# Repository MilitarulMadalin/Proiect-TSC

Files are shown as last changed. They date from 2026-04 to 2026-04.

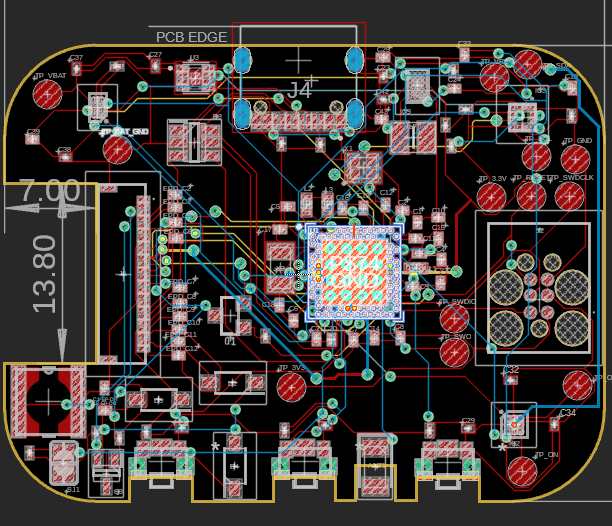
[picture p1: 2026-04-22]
Images/2d.png

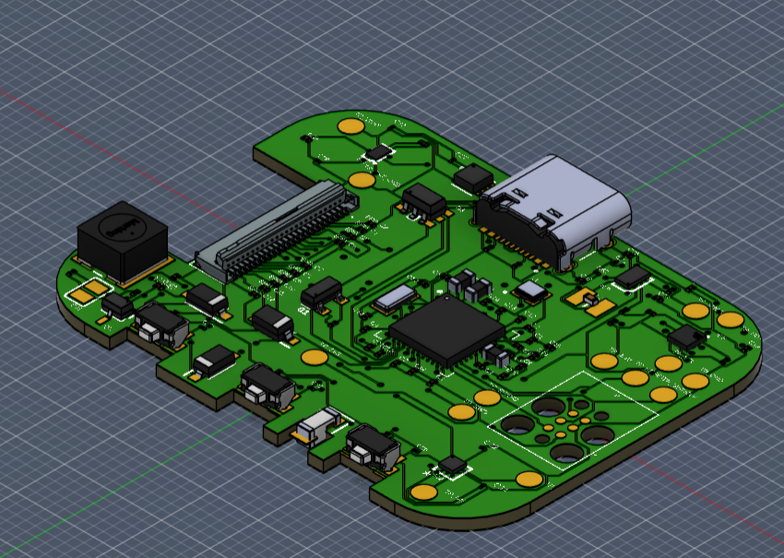
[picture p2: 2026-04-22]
Images/exploded.png

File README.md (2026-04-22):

# InkTime

## Cuprins

1. [Schemă bloc](#1-schemă-bloc)
2. [Bill of Materials (BOM)](#2-bill-of-materials-bom)
3. [Descrierea hardware detaliată](#3-descrierea-hardware-detaliată)
4. [Mapare pini nRF52840](#4-mapare-pini-nrf52840)
5. [Design log](#5-decizii-de-design)

---

## 1. Schemă bloc

```
                  +--------------+      +-------------+
                  |   E-Paper    |      |    LiPo     |
                  |  Drive Circ. |      |   Charger   +
                  +------+-------+      +------+------+
                         |                     |
                         | EPD_PINS            | I2C, PMIC_INT       +-----------+
                         v                     |                     |   Fuel    |
  +-----------+   +--------------+             |            I2C      |   Gauge   |
  |  E-Paper  |<--+   E-Paper    |             |        +----------->|           |
  |   1.5"    |   |    Conn.     |             |        |            +-----------+
  +-----------+   +------+-------+             |        |
                         |                     |        |            +-----------+
                         |  SPI                |        |            |   USB-C   |
                         v                     v        |            |    J4     |
                  +----------------------------+--------+------+     +-----+-----+
                  |                                            |           |
                  |              nRF52840   (U1)               |<----------+
                  |                                            |  D+, D-
                  |                                            |<--------+
                  +--+--------+--------+--------+------+-------+         |
                     |        |        |        |      |                 |
                     | I2C    | I2C    | ANT1   | SWD  | 3xGPIO          | D+, D-
                     |        | HAPT.  |        |      |                 |
                     v        | EN     v        v      v           +-----+-----+
                  +-------+   |   +--------+ +-----+ +---------+   |    ESD    |
                  |  IMU  |   |   | Antena | | SWD | | Butoane |   | Protection|
                  |BMA423 |   |   |  2.4   | | J2  | +---------+   +-----------+
                  +-------+   |   +--------+ +-----+
                              v
                          +-------+
                          |Haptic |
                          |DRV2605|
                          +-------+
```

---

## 2. Bill of Materials (BOM)

| Desig. (ref.) | Valoare / Part Number | Funcție în circuit | Pachet | Cant. | JLCPCB | Datasheet |
|---|---|---|---|---|---|---|
| U1 | nRF52840-QIAA | MCU BLE 5 / 2.4 GHz, Cortex-M4F, 1 MB Flash  | aQFN73 | 1 | [C190794](https://jlcpcb.com/partdetail/C190794) | [PDF](https://infocenter.nordicsemi.com/pdf/nRF52840_PS_v1.7.pdf) |
| IC1 | BQ25180YBGR | Încărcător LiPo 1-cell, programabil I2C | DSBGA-8 0.4mm | 1 | [C965556](https://jlcpcb.com/partdetail/C965556) | [PDF](https://www.ti.com/lit/ds/symlink/bq25180.pdf) |
| U3 | MAX17048G+T10 | Fuel gauge ModelGauge 1-cell, I2C | TDFN-8 | 1 | [C129977](https://jlcpcb.com/partdetail/C129977) | [PDF](https://www.analog.com/media/en/technical-documentation/data-sheets/MAX17048-MAX17049.pdf) |
| IC9 | RT6160AWSC | Buck-Boost 3V3, 2A (rail principal) | WL-CSP-15 | 1 | [C58559](https://jlcpcb.com/partdetail/C58559) | [PDF](https://www.richtek.com/assets/product_file/RT6160A/DS6160A-02.pdf) |
| IC3 | BMA423 | Accelerometru 3-axis, step counter, wrist-tilt | LGA-12 | 1 | [C553690](https://jlcpcb.com/partdetail/C553690) | [PDF](https://www.bosch-sensortec.com/media/boschsensortec/downloads/datasheets/bst-bma423-ds000.pdf) |
| IC2 | DRV2605YZFR | Driver haptic ERM/LRA, 123 efecte, I2C | DSBGA-9 | 1 | [C92482](https://jlcpcb.com/partdetail/C92482) | [PDF](https://www.ti.com/lit/ds/symlink/drv2605.pdf) |
| Q1 | DMG2305UX-7 (20V/4.2A) | P-MOSFET load-switch rail EPD | SOT-23 | 1 | [C114005](https://jlcpcb.com/partdetail/C114005) | [PDF](https://www.diodes.com/assets/Datasheets/DMG2305UX.pdf) |
| Q3 | SI1308EDL-T1-GE3 | N-MOSFET pentru boost charge-pump EPD | SOT-23 | 1 | [C294574](https://jlcpcb.com/partdetail/C294574) | [PDF](https://www.vishay.com/docs/66632/si1308edl.pdf) |
| D3 | USBLC6-2SC6Y | TVS diode array, protecție ESD pe USB D± | SOT-23-6 | 1 | [C7519](https://jlcpcb.com/partdetail/C7519) | [PDF](https://www.st.com/resource/en/datasheet/usblc6-2.pdf) |
| D2, D4, D5 | MBR0530 | Diodă Schottky 30V pentru charge-pump EPD | SOD-123 | 3 | [C131850](https://jlcpcb.com/partdetail/C131850) | [PDF](https://www.onsemi.com/pdf/datasheet/mbr0520-d.pdf) |
| ANT1 | 2450AT18B100E | Antenă ceramică chip 2.4 GHz, Johanson | 3216 | 1 | [C76907](https://jlcpcb.com/partdetail/C76907) | [PDF](https://www.johansontechnology.com/datasheets/2450AT18B100E.pdf) |
| X1 | NX2016SA 32 MHz ±10 ppm | Cristal HF pentru radio și CPU | 2016 | 1 | [C255982](https://jlcpcb.com/partdetail/C255982) | [PDF](https://www.ndk.com/images/products/catalog/c_NX2016SA-STD-CRA-2_e.pdf) |
| X2 | ABS07-120 32.768 kHz | Cristal LF pentru RTC (low-power) | 3215 | 1 | [C32346](https://jlcpcb.com/partdetail/C32346) | [PDF](https://abracon.com/Resonators/abs07-120.pdf) |
| L1 | 3.9 nH | RF match filtru π — inductor serie antenă | 0402 | 1 | [C1789](https://jlcpcb.com/partdetail/C1789) | — |
| L3 | 15 nH | RF match filtru π — inductor paralel | 0402 | 1 | [C1794](https://jlcpcb.com/partdetail/C1794) | — |
| L2 | 10 µH | DCDC intern nRF52840 (pin DCC) | 0402 | 1 | [C1046](https://jlcpcb.com/partdetail/C1046) | — |
| L5 | WE-TPC 744043680, 68 µH | Boost e-paper (rail VGH / VGL) | 4828 | 1 | [C492815](https://jlcpcb.com/partdetail/C492815) | [PDF](https://www.we-online.com/catalog/datasheet/744043680.pdf) |
| L7 | FTC252012SR47MBCA, 0.47 µH | Inductor putere pentru RT6160 | 2520 | 1 | [C123046](https://jlcpcb.com/partdetail/C123046) | — |
| J4 | KH-TYPE-C-16P | Conector USB-C receptacle (16 pini) | SMT | 1 | [C165948](https://jlcpcb.com/partdetail/C165948) | — |
| J1 | Molex 503480-2400 | Conector baterie LiPo, 2-pin pitch 1.5 mm | SMT | 1 | [C518439](https://jlcpcb.com/partdetail/C518439) | [PDF](https://www.molex.com/pdm_docs/sd/5034802400_sd.pdf) |
| J2 | TC2030-IDC (Tag-Connect) | Footprint debug SWD (pogo-pins, fără receptacle) | — | 1 | (doar footprint) | [PDF](https://www.tag-connect.com/wp-content/uploads/bsk-pdf-manager/TC2030-IDC.pdf) |
| SW_UP, SW_DN, SW_ENT | EVP-AKE31A | Buton tactil side-push 4.5×3.5 mm | SMT | 3 | [C719888](https://jlcpcb.com/partdetail/C719888) | [PDF](https://industrial.panasonic.com/cdbs/www-data/pdf/ATV0000/ATV0000CE11.pdf) |
| C11, C12 | 100 nF / 10V (X7R) | Decuplare locală IC-uri digitale | 0201 | 2 | [C106250](https://jlcpcb.com/partdetail/C106250) | — |
| C5, C7, C8 | 100 µF / 6.3V | Bulk buck-boost RT6160 | 0201 | 3 | [C19702](https://jlcpcb.com/partdetail/C19702) | — |
| C19 | 100 µF / 6.3V | Bulk rail VBAT | 0201 | 1 | [C19702](https://jlcpcb.com/partdetail/C19702) | — |
| C6, C14, C20, C21 | 4.7 µF / 10V (X7R) | Decuplare nRF (DEC*) | 0201 | 4 | [C19666](https://jlcpcb.com/partdetail/C19666) | — |
| C15 | 1.0 µF / 10V | Decuplare VREG nRF | 0201 | 1 | [C15849](https://jlcpcb.com/partdetail/C15849) | — |
| C39 | 10 µF / 6.3V | Bulk IC1 (charger) | 0201 | 1 | [C15850](https://jlcpcb.com/partdetail/C15850) | — |
| C43 | 4.7 µF | Intrare IC2 (driver haptic) | 0201 | 1 | [C19666](https://jlcpcb.com/partdetail/C19666) | — |
| C1-EP-DR, C24 | 10 µF | Filtre intrare driver EPD / RT6160 | 0201 | 2 | [C15850](https://jlcpcb.com/partdetail/C15850) | — |
| C2-EP-DR | 4.7 µF / 25V | Bulk intrare boost EPD | 0201 | 1 | [C19666](https://jlcpcb.com/partdetail/C19666) | — |
| C25, C33 | 22 µF | Ieșire RT6160 (3V3) | 0201 | 2 | [C45783](https://jlcpcb.com/partdetail/C45783) | — |
| C17, C18 | 12 µF | Filtre DCDC intern nRF | 0201 | 2 | [C162698](https://jlcpcb.com/partdetail/C162698) | — |
| C16 | 47 nF | Filtru control-loop RT6160 | 0201 | 1 | [C113010](https://jlcpcb.com/partdetail/C113010) | — |
| C9 | 820 pF | Decuplare DEC6 nRF | 0201 | 1 | [C1603](https://jlcpcb.com/partdetail/C1603) | — |
| C1, C2 | 12 pF (NP0 / C0G) | Load-caps pentru X1 (32 MHz) | 0201 | 2 | [C1570](https://jlcpcb.com/partdetail/C1570) | — |
| C3, C4 | 1 pF | RF match (π) — shunt | 0201 | 2 | [C1552](https://jlcpcb.com/partdetail/C1552) | — |
| C10, C13, C22 | N.C. (Not Connected) | Rezervate — neplasate la fabricație | 0201 | 3 | (nu se lipește) | — |
| C23, C27, C29, C30, C31, C32, C34, C37, C38, C42 | GRM011R60J152KE01L, 1.5 nF | Filtre RF / bypass high-freq | 0201 | 10 | [C400827](https://jlcpcb.com/partdetail/C400827) | [PDF](https://www.murata.com/en-us/products/productdata/8796840689694/GCM155C71A225KE36-01A.pdf)  |
| EPD_C1, EPD_C2, EPD_C6, EPD_C7, EPD_C8, EPD_C9, EPD_C10, EPD_C11, EPD_C12 | 1 µF / 50V (X7R) | Flying caps charge-pump pentru VGH/VGL | 0201 | 9 | [C105948](https://jlcpcb.com/partdetail/C105948) | — |
| EPD_C5 | 0.1 µF / 50V | Decuplare driver EPD | 0201 | 1 | [C14663](https://jlcpcb.com/partdetail/C14663) | — |
| R1_USB, R2_USB | 5.1 kΩ 1% (CC1 / CC2) | Pull-down USB-C — configurare device UFP | 0201 | 2 | [C98220](https://jlcpcb.com/partdetail/C98220) | — |
| R1_EP_DR, R2_EP_DR | 10 kΩ 1% | Divider / gate pull pentru boost EPD | 0201 | 2 | [C25744](https://jlcpcb.com/partdetail/C25744) | — |
| R_PWR_EPD, R_TYPE_SEL | 10 kΩ 1% | Selector tip panou EPD / enable rail | 0201 | 2 | [C25744](https://jlcpcb.com/partdetail/C25744) | — |
| R2, R3, R4 | 0 Ω | Jumperi / pull-uri I2C (SDA, SCL, ALERT) | 0201 | 3 | [C17168](https://jlcpcb.com/partdetail/C17168) | — |
| R5, R7, R8 | 10 kΩ 1% | Pull-up butoane SW_UP, SW_DN, SW_ENT | 0201 | 3 | [C25744](https://jlcpcb.com/partdetail/C25744) | — |
| R9 | 10 kΩ 1% | MR (TS / mode-select) pe BQ25180 | 0201 | 1 | [C25744](https://jlcpcb.com/partdetail/C25744) | — |
| R17, R18 | 3.3 kΩ 1% | Feedback / setare tensiune RT6160 | 0201 | 2 | [C22975](https://jlcpcb.com/partdetail/C22975) | — |
| TP_3V3, TP_3.3V, TP_VREG, TP_VBAT, TP_BAT_GND, TP_GND, TP_RESET, TP_SDA, TP_SCL, TP_SWDCLK, TP_SWDIO, TP_SWO, TP_ON, TP_OP | Pad 20 mil | Puncte de test pentru măsurători / debug | 20R pad | 14 | (doar footprint) | — |
| SJ1 | Solder jumper | Select hardware (bootloader / mod) | 0201 jumper | 1 | (doar footprint) | — |

### Off-board

| Componentă | Valoare / Model | Legătură |
|---|---|---|
| Baterie | LiPo 483450, 3.7V, 2400 mAh | Conector J1 (Molex 503480-2400) |
| Panou e-paper | GDEW0154M09, 1.54" 200×200 px, SPI | Conector FPC 24 pini (nu e pe placă — se leagă prin cablaj) |
| Motor vibrație | ERM 10×2.7 mm, 3V nominal | Pini OUT+ / OUT− ai DRV2605 |

---

## 3. Descrierea hardware detaliată

### 3.1. Alimentare

Lanțul de alimentare respectă o arhitectură clasică **charger → baterie → regulator**, adaptată pentru low-power:

1. **Intrare USB-C (J4)** — 5V / max 500 mA. Liniile D+/D− sunt protejate de **USBLC6-2 (D3)**, diodă TVS cu capacitate mică care nu afectează eye-pattern-ul USB 2.0 Full-Speed.
2. **Încărcător BQ25180 (IC1)** — integrează charger liniar 1-cell LiPo cu până la 500 mA, path management, detecție over-voltage 18V și **ship-mode**. Configurabil pe I2C: curent de încărcare, prag de terminare, temperatură. Pinul **INT** este conectat la nRF pentru evenimente.
3. **Baterie LiPo 2400 mAh** conectată la J1. Pinul TS/MR al BQ25180 nu folosește termistor.
4. **Fuel gauge MAX17048 (U3)** — măsoară direct tensiunea bateriei cu algoritmul **ModelGauge**, oferind SoC și rata de descărcare. Pinul ALERT este rutat la nRF pentru notificări de low-battery.
5. **Buck-Boost RT6160 (IC9)** — convertor **step-up/step-down** la **3V3 fix**, eficiență până la 95%. Alegerea unui buck-boost e critică: o baterie LiPo ajunge la ~3.0V la descărcare, iar un LDO ar avea dropout, în timp ce un buck pur nu ar putea menține 3V3 când bateria e sub acest nivel. RT6160 oferă continuitate până la ~2.5V cu regulare menținută.
6. **Load-switch Q1 (DMG2305UX-7)** — P-MOSFET care deconectează complet rail-ul boost al e-paper-ului în stand-by.

**Rețeaua RF**: antena ceramică ANT1 e alimentată prin **filtru π** pentru match la 50 Ω și filtrare armonici. Traseul de la pinul **ANT** al nRF la antenă respectă **controlled impedance** 50 Ω.

### 3.2. Microcontroller și clock

**nRF52840** rulează cu două cristale:

- **X1 = 32 MHz (NX2016SA)** pe pinii XC1/XC2, cristal principal pentru radio și HFCLK. Toleranță ≤ 40 ppm.
- **X2 = 32.768 kHz (ABS07)** pe pinii P0.00/XL1, P0.01/XL2, clock low-power pentru RTC și sleep. Toleranță 20 ppm, consum < 1 µA.

Decuplarea rail-urilor interne folosește 4.7 µF + 100 nF + 1 µF + 100 pF conform reference design Nordic. **L4 + L6**împreună cu C14 + C15 + C20 implementează DC/DC intern care reduce consumul cu ~30% față de modul LDO.

### 3.3. Display e-paper

E-paper-ul **GDEW0154M09** are nevoie de patru rail-uri: +15V (VGH), −15V (VGL), +22V (VPP), −20V (VEE). Driver circuit-ul de pe Sheet 2 folosește:

- **Boost cu SI1308 + L5 + MBR0530** care generează VGH/VGL prin charge-pump multi-stage.
- **9× condensatori 1µF/50V** — flying caps pentru stagele charge-pump.

Controlul e pe SPI + semnale discrete: RST, BUSY, D/C, CS. Rail-ul EPD_3V3 se activează doar când se refresh-uiește display-ul; în rest, e-paper-ul menține imaginea fără alimentare.

### 3.4. Senzori și actuatori

- **BMA423 (IC3)** — accelerometru 3-axis 12-bit cu engine de pași, detecție tap/double-tap și wrist-tilt. Întreruperi: INT1, INT2. Interfața I2C, adresa 0x19.
- **DRV2605 (IC2)** — driver haptic pentru motoare ERM sau LRA. Conține **librărie pre-programată cu 123 efecte**, plus mod real-time. Activat prin HAPTIC_EN pentru a elimina complet consumul în idle. Bobina motorului e conectată la pinii OUT+/OUT−.

### 3.5. Butoane și debug

Cele 3 butoane sunt conectate GPIO cu GND, cu pull-up intern activat software. **Fără debounce hardware** , se face în firmware.

Conectorul **TC2030-IDC (J2)** e un footprint 6-pin fără receptacle fizic, debugger-ul are pogo-pins care fac contact direct pe PCB, economisind componenta și spațiu. Semnale: SWDIO, SWDCLK, SWO, RESET, 3V3, GND.

---

## 4. Mapare pini nRF52840

Mapare extrasă din schematic (InkTime v6, Sheet 1 + Sheet 2):

| Pin nRF52840 | Nume net | Funcție firmware | Destinație periferic |
|---|---|---|---|
| **Alimentare**  | | | |
| VDD / VDDH | 3V3 | Alimentare digital | Rail 3V3 (de la RT6160) |
| VBUS | VBUS | Detecție USB plug-in | USB 5V |
| DEC1..DEC6 | DEC* | Decuplare internă | Local 100 nF × 6 |
| DCC / DCCH | LX1 / LX2 | DC-DC intern (SMPS) | L4 + L6 (10 µH) + filtre |
| **Clock** | | | |
| P0.00 / XL1 | XL1 | Cristal RTC 32.768 kHz | X2 |
| P0.01 / XL2 | XL2 | Cristal RTC 32.768 kHz | X2 |
| XC1 / XC2 | XC1 / XC2 | Cristal HF 32 MHz | X1 |
| **Radio** | | | |
| ANT | RF | Ieșire RF | filtru π → ANT1 |
| **USB** | | | |
| D+ | D+ | USB 2.0 Full-Speed | J4 (prin USBLC6-2) |
| D- | D- | USB 2.0 Full-Speed | J4 (prin USBLC6-2) |
| **Debug** | | | |
| SWDCLK | SWDCLK | Clock debug | J2 pin 4 |
| SWDIO | SWDIO | Data debug | J2 pin 2 |
| P0.18 / nRESET  | RESET | Reset hardware | J2 pin 5 + TP_RESET |
| **SPI (TWIM1)** — e-paper | | | |
| P0.13 | EPD_SCK / SCK  | Clock SPI | FPC pin 5 |
| P0.14 | EPD_MOSI / MOSI| Data SPI master→slave | FPC pin 4 |
| P0.15 | EPD_CS | Chip-select | FPC pin 6 |
| P0.16 | EPD_DC | Data / Command | FPC pin 7 |
| P0.17 | EPD_RST | Reset display | FPC pin 8 |
| P0.19 | EPD_BUSY | Busy-in (drive done) | FPC pin 9 |
| **I2C (TWIM0)** — senzori | | | |
| P0.24 | SDA | I2C data | BMA423 · DRV2605 · MAX17048 · BQ25180 |
| P0.25 | SCL | I2C clock | BMA423 · DRV2605 · MAX17048 · BQ25180 |
| **Întreruperi** | | | |
| P0.22 | IMU_INT1 | IMU: pași / tap | BMA423 pin 5 |
| P0.23 | IMU_INT2 | IMU: wake-up | BMA423 pin 6 |
| P0.20 | ALERT | Fuel gauge low-bat | MAX17048 pin 5 |
| P0.21 | PMIC_INT | Charger events | BQ25180 pin A1 |
| **Butoane** | | | |
| P0.04 | SW_UP | Buton sus | SW_UP (push-to-GND) |
| P0.05 | SW_DN | Buton jos | SW_DN (push-to-GND) |
| P0.06 | SW_ENT | Buton enter | SW_ENT (push-to-GND) |
| **Control** | | | |
| P0.26 | HAPTIC_EN | Enable DRV2605 + boost EPD | IC2 pin EN / Q3 gate |
| P0.27 | EPD_PWR | Load-switch panou e-paper | Q1 gate |

---

## 5. Decizii de design

- **Utilizarea componentelor SMD în capsule mici** Am ales respectarea strictă a dimensiunilor impuse (0201 pentru rezistențe și condensatoare ≤100nF, respectiv 0402 pentru valori mai mari) pentru a reduce dimensiunea totală a PCB-ului. Această alegere contribuie la integrarea mai ușoară în carcasă și la un design compact, esențial pentru dispozitive portabile.
- **Amplasarea componentelor doar pe layer-ul TOP** Toate componentele au fost plasate pe TOP pentru a simplifica procesul de asamblare și pentru a evita costuri suplimentare asociate montajului pe ambele fețe. În plus, această abordare reduce riscul de erori mecanice și facilitează inspecția vizuală.
- **Excluderea planului de masă sub antenă** Zona de sub antenă a fost complet decuplată de planul de masă și nu au fost rutate semnale acolo. Aceasta previne detunarea antenei și pierderile de eficiență, asigurând performanță RF optimă.
- **Silkscreen minimalist și lizibil** Am inclus doar denumirile componentelor pentru a evita aglomerarea vizuală. Un silkscreen curat ajută la identificarea rapidă a componentelor și îmbunătățește mentenanța.
- **Utilizarea unui PCB cu 4 layere** Am ales o structură pe 4 layere (TOP, GND plane, POWER plane, BOTTOM) pentru a îmbunătăți semnificativ integritatea semnalului și stabilitatea alimentării.

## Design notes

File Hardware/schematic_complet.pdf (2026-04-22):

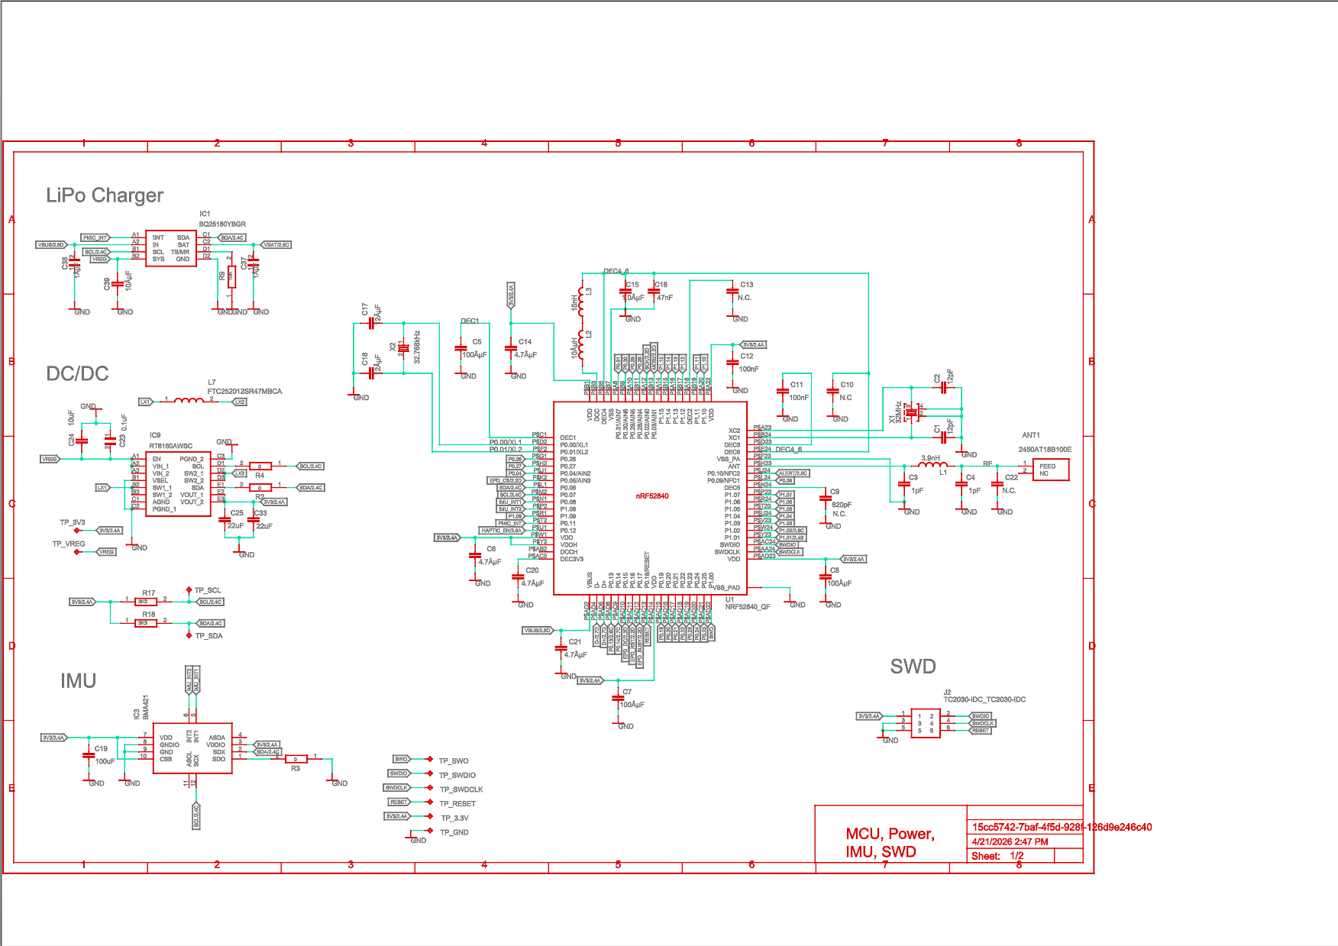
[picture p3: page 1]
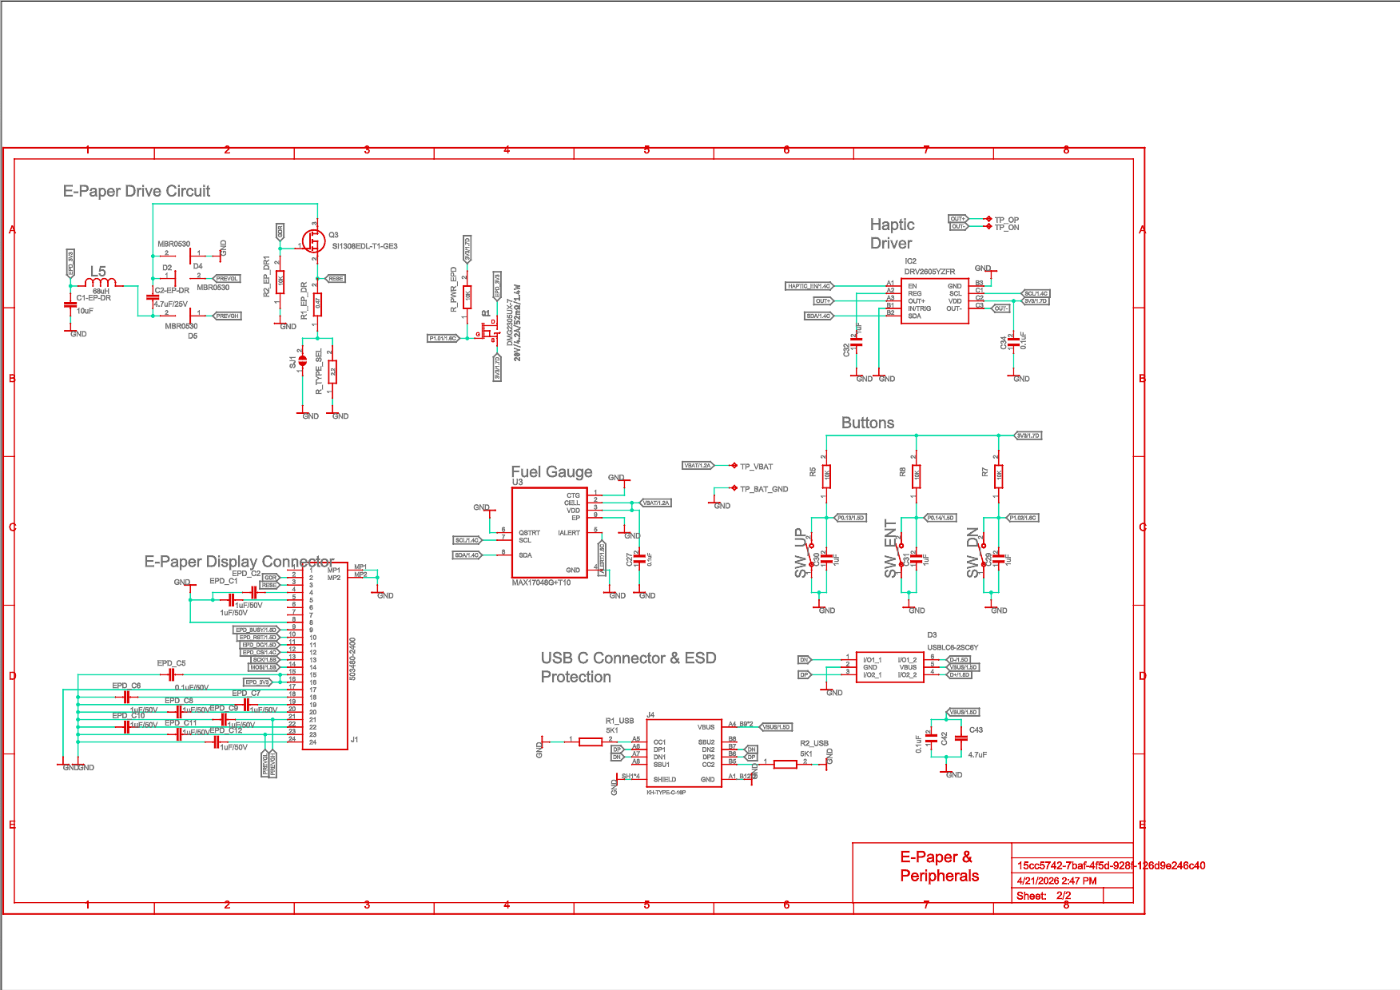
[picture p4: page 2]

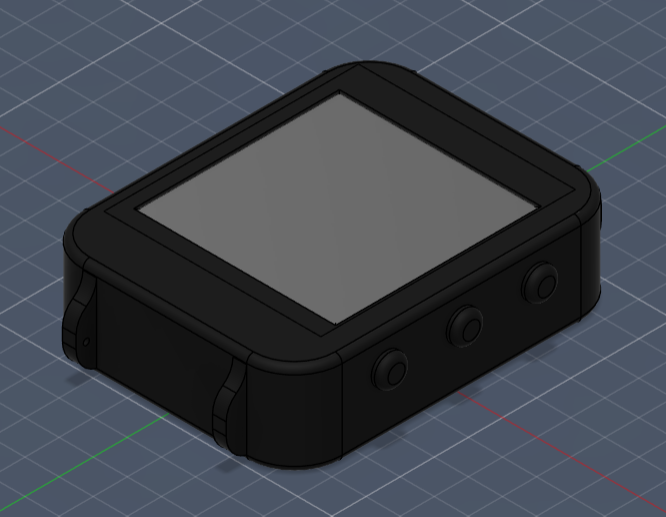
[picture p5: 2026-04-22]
Images/full.png

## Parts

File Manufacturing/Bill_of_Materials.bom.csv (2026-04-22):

ANT1 | 5.94 | -14.80 | 270.00 | 2450AT18B100E_2450AT18B100E | 2450AT18B100E_ANTC3216X140N
C1 | 9.20 | 3.96 | 90.00 | 12pF | NORDIC_NRF_3_RESC0201_L
C1-EP-DR | -14.83 | -8.75 | 90.00 | 10uF | NORDIC_NRF_3_RESC0201_L
C10 | 10.77 | 4.30 | 180.00 | N.C | NORDIC_NRF_3_RESC0201_L
C11 | 9.03 | 2.75 | 0.00 | 100nF | NORDIC_NRF_3_RESC0201_L
C12 | 6.75 | 5.28 | 90.00 | 100nF | NORDIC_NRF_3_RESC0201_L
C13 | 5.00 | 5.05 | 90.00 | N.C. | NORDIC_NRF_3_RESC0201_L
C14 | 5.85 | -4.93 | 270.00 | 4.7µF | NORDIC_NRF_3_RESC0201_L
C15 | 10.75 | 2.68 | 90.00 | 1.0µF | NORDIC_NRF_3_RESC0201_L
C16 | 3.40 | 5.06 | 90.00 | 47nF | NORDIC_NRF_3_RESC0201_L
C17 | -1.40 | 3.41 | 180.00 | 12µF | NORDIC_NRF_3_RESC0201_L
C18 | -1.44 | -2.40 | 90.00 | 12µF | NORDIC_NRF_3_RESC0201_L
C19 | 21.05 | 14.27 | 270.00 | 100uF | NORDIC_NRF_3_RESC0201_L
C2 | 8.01 | 4.90 | 0.00 | 12pF | NORDIC_NRF_3_RESC0201_L
C2-EP-DR | -14.81 | -10.47 | 0.00 | 4.7uF/25V | NORDIC_NRF_3_RESC0201_L
C20 | 2.55 | -5.03 | 270.00 | 4.7µF | NORDIC_NRF_3_RESC0201_L
C21 | 1.45 | -4.98 | 270.00 | 4.7µF | NORDIC_NRF_3_RESC0201_L
C22 | 10.93 | -0.70 | 270.00 | N.C. | NORDIC_NRF_3_RESC0201_L
C23 | 6.55 | 15.18 | 270.00 | GRM011R60J152KE01L_2_GRM011R60J152KE01L | GRM011R60J152KE01L_2_CAPC0201X13N
C24 | 12.01 | 14.20 | 180.00 | 10uF | NORDIC_NRF_3_RESC0201_L
C25 | 6.54 | 16.60 | 180.00 | 22uF | NORDIC_NRF_3_RESC0201_L
C27 | -10.95 | 15.96 | 270.00 | GRM011R60J152KE01L_2_GRM011R60J152KE01L | GRM011R60J152KE01L_2_CAPC0201X13N
C29 | 13.06 | -11.85 | 0.00 | GRM011R60J152KE01L_2_GRM011R60J152KE01L | GRM011R60J152KE01L_2_CAPC0201X13N
C3 | 9.29 | 1.60 | 0.00 | 1pF | NORDIC_NRF_3_RESC0201_L
C30 | -8.92 | -11.85 | 0.00 | GRM011R60J152KE01L_2_GRM011R60J152KE01L | GRM011R60J152KE01L_2_CAPC0201X13N
C31 | 2.10 | -11.65 | 0.00 | GRM011R60J152KE01L_2_GRM011R60J152KE01L | GRM011R60J152KE01L_2_CAPC0201X13N
C32 | 16.32 | -8.15 | 0.00 | GRM011R60J152KE01L_2_GRM011R60J152KE01L | GRM011R60J152KE01L_2_CAPC0201X13N
C33 | 12.79 | 16.80 | 270.00 | 22uF | NORDIC_NRF_3_RESC0201_L
C34 | 19.65 | -11.54 | 270.00 | GRM011R60J152KE01L_2_GRM011R60J152KE01L | GRM011R60J152KE01L_2_CAPC0201X13N
C37 | -17.01 | 15.75 | 270.00 | GRM011R60J152KE01L_2_GRM011R60J152KE01L | GRM011R60J152KE01L_2_CAPC0201X13N
C38 | -17.85 | 8.97 | 0.00 | GRM011R60J152KE01L_2_GRM011R60J152KE01L | GRM011R60J152KE01L_2_CAPC0201X13N
C39 | -20.39 | 10.34 | 0.00 | 10µF | NORDIC_NRF_3_RESC0201_L
C4 | 11.00 | 1.11 | 90.00 | 1pF | NORDIC_NRF_3_RESC0201_L
C42 | 6.56 | 13.39 | 0.00 | GRM011R60J152KE01L_2_GRM011R60J152KE01L | GRM011R60J152KE01L_2_CAPC0201X13N
C43 | 6.42 | 11.85 | 180.00 | 4.7uF | NORDIC_NRF_3_RESC0201_L
C5 | -0.77 | 5.15 | 0.00 | 100µF | NORDIC_NRF_3_RESC0201_L
C6 | -0.35 | -3.58 | 270.00 | 4.7µF | NORDIC_NRF_3_RESC0201_L
C7 | 4.25 | -5.08 | 270.00 | 100µF | NORDIC_NRF_3_RESC0201_L
C8 | 7.85 | -4.93 | 270.00 | 100µF | NORDIC_NRF_3_RESC0201_L
C9 | 8.78 | -0.95 | 0.00 | 820pF | NORDIC_NRF_3_RESC0201_L
D2 | -5.01 | -8.36 | 180.00 | ESP32_C6_LIBRARY_5_MBR0530 | ESP32_C6_LIBRARY_5_SOD3716X135N
D3 | -7.94 | 10.07 | 0.00 | ESP32_C6_LIBRARY_3_USBLC6-2SC6Y | ESP32_C6_LIBRARY_3_SOT95P280X145-6N
D4 | -4.84 | -14.74 | 90.00 | ESP32_C6_LIBRARY_5_MBR0530 | ESP32_C6_LIBRARY_5_SOD3716X135N
D5 | -10.68 | -9.64 | 180.00 | ESP32_C6_LIBRARY_5_MBR0530 | ESP32_C6_LIBRARY_5_SOD3716X135N
EPD_C1 | -9.42 | 5.07 | 180.00 | 1uF/50V | NORDIC_NRF_3_RESC0201_L
EPD_C10 | -9.13 | -4.23 | 180.00 | 1uF/50V | NORDIC_NRF_3_RESC0201_L
EPD_C11 | -9.19 | -5.17 | 0.00 | 1uF/50V | NORDIC_NRF_3_RESC0201_L
EPD_C12 | -9.17 | -6.23 | 180.00 | 1uF/50V | NORDIC_NRF_3_RESC0201_L
EPD_C2 | -9.43 | 6.07 | 180.00 | 1uF/50V | NORDIC_NRF_3_RESC0201_L
EPD_C5 | -9.41 | 3.97 | 180.00 | 0.1uF/50V | NORDIC_NRF_3_RESC0201_L
EPD_C6 | -9.35 | 2.75 | 180.00 | 1uF/50V | NORDIC_NRF_3_RESC0201_L
EPD_C7 | -9.06 | -1.05 | 180.00 | 1uF/50V | NORDIC_NRF_3_RESC0201_L
EPD_C8 | -9.05 | -2.23 | 180.00 | 1uF/50V | NORDIC_NRF_3_RESC0201_L
EPD_C9 | -9.08 | -3.25 | 180.00 | 1uF/50V | NORDIC_NRF_3_RESC0201_L
IC1 | -15.37 | 12.77 | 180.00 | BQ25180YBGR_BQ25180YBGR | BQ25180YBGR_BGA8C40P2X4_100X155X50
IC2 | 16.60 | -11.57 | 0.00 | DRV2605YZFR_DRV2605YZFR | DRV2605YZFR_BGA9C50P3X3_144X144X62
IC3 | 17.22 | 12.00 | 180.00 | BMA423_BMA423 | BMA423_BMA423
IC9 | 9.17 | 14.44 | 180.00 | RT6160AWSC_RT6160AWSC | RT6160AWSC_BGA15C40P3X5_140X230X60
J1 | -13.20 | 0.00 | 270.00 | 503480-2400_503480-2400 | 503480-2400_5034802400
J2 | 18.50 | -1.67 | 90.00 | TC2030-IDC_TC2030-IDC | TC2030-IDC_TC2030IDC
J4 | 0.05 | 14.06 | 180.00 | KH-TYPE-C-16P_KH-TYPE-C-16P | KH-TYPE-C-16P_KINGHELM_KH-TYPE-C-16P
L1 | 9.06 | 0.45 | 0.00 | 3.9nH | NORDIC_NRF_2_RESC0402_L
L2 | 0.65 | 5.33 | 90.00 | 10µH | NORDIC_NRF_2_RESC0402_L
L3 | 2.30 | 5.31 | 270.00 | 15nH | NORDIC_NRF_2_RESC0402_L
L5 | -19.13 | -9.82 | 0.00 | ESP32_C6_LIBRARY_2_744043680IND_4828-WE-TPC_WRE | ESP32_C6_LIBRARY_2_IND_4828-WE-TPC_WRE
L7 | 8.84 | 10.44 | 0.00 | MLP2016SR47MT0S1_FTC252012SR47MBCA | MLP2016SR47MT0S1_INDC2016X100N
Q1 | -5.25 | -3.19 | 90.00 | 20V/4.2A/52mΩ/1.4W | ESP32_C6_LIBRARY_4_ESP32_C6_LIBRARY_4_ESP32_C6_LIBRARY_4_ESP32_C6_LIBRARY_4_ESP32_WROVER_SPARKFUN-DISCRETESEMI_SOT23-3
Q3 | -14.71 | -15.29 | 270.00 | ESP32_C6_LIBRARY_6_SI1308EDL-T1-GE3 | ESP32_C6_LIBRARY_6_SOT65P210X110-3N
R17 | 12.89 | 12.62 | 270.00 | ERA-1AEB3401C_CPF0201D7K68C1 | ERA-1AEB3401C_0201
R18 | 11.76 | 9.81 | 180.00 | ERA-1AEB3401C_CPF0201D7K68C1 | ERA-1AEB3401C_0201
R1_EP_DR | -15.48 | -12.21 | 0.00 | ERA-1AEB3401C_CPF0201D7K68C1 | ERA-1AEB3401C_0201
R1_USB | 1.72 | 9.91 | 180.00 | ERA-1AEB3401C_CPF0201D7K68C1 | ERA-1AEB3401C_0201
R2 | 11.94 | 15.59 | 0.00 | ERA-1AEB3401C_CPF0201D7K68C1 | ERA-1AEB3401C_0201
R2_EP_DR1 | -13.70 | -12.61 | 0.00 | ERA-1AEB3401C_CPF0201D7K68C1 | ERA-1AEB3401C_0201
R2_USB | -1.24 | 9.99 | 0.00 | ERA-1AEB3401C_CPF0201D7K68C1 | ERA-1AEB3401C_0201
R3 | 21.01 | 12.12 | 180.00 | ERA-1AEB3401C_CPF0201D7K68C1 | ERA-1AEB3401C_0201
R4 | 11.32 | 11.41 | 180.00 | ERA-1AEB3401C_CPF0201D7K68C1 | ERA-1AEB3401C_0201
R5 | -11.66 | -12.11 | 0.00 | ERA-1AEB3401C_CPF0201D7K68C1 | ERA-1AEB3401C_0201
R7 | 10.10 | -12.01 | 0.00 | ERA-1AEB3401C_CPF0201D7K68C1 | ERA-1AEB3401C_0201
R8 | -1.04 | -12.01 | 0.00 | ERA-1AEB3401C_CPF0201D7K68C1 | ERA-1AEB3401C_0201
R9 | -13.91 | 15.96 | 90.00 | ERA-1AEB3401C_CPF0201D7K68C1 | ERA-1AEB3401C_0201
R_PWR_EPD | -2.50 | -4.79 | 180.00 | ERA-1AEB3401C_CPF0201D7K68C1 | ERA-1AEB3401C_0201
R_TYPE_SEL | -20.57 | -13.71 | 0.00 | ERA-1AEB3401C_CPF0201D7K68C1 | ERA-1AEB3401C_0201
SJ1 | -17.96 | -14.51 | 270.00 |  | ESP32_C6_LIBRARY_7_JUMPER_SJ
SW_DN | 11.50 | -14.13 | 180.00 | 2025-10-22_07-23-44_LIBRARY_EVP-AKE31ASW_EVP-AKE31A_PAN | 2025-10-22_07-23-44_LIBRARY_SW_EVP-AKE31A_PAN
SW_ENT | 0.52 | -14.04 | 180.00 | 2025-10-22_07-23-44_LIBRARY_EVP-AKE31ASW_EVP-AKE31A_PAN | 2025-10-22_07-23-44_LIBRARY_SW_EVP-AKE31A_PAN
SW_UP | -10.48 | -14.04 | 180.00 | 2025-10-22_07-23-44_LIBRARY_EVP-AKE31ASW_EVP-AKE31A_PAN | 2025-10-22_07-23-44_LIBRARY_SW_EVP-AKE31A_PAN
TP_3.3V | 14.82 | 5.88 | 0.00 | HECTOR_WATCH_1_TPTP20R | HECTOR_WATCH_1_TP20R
TP_3V3 | -0.48 | -8.72 | 0.00 | HECTOR_WATCH_1_TPTP20R | HECTOR_WATCH_1_TP20R
TP_BAT_GND | -13.84 | 9.53 | 0.00 | HECTOR_WATCH_1_TPTP20R | HECTOR_WATCH_1_TP20R
TP_GND | 21.31 | 8.78 | 0.00 | HECTOR_WATCH_1_TPTP20R | HECTOR_WATCH_1_TP20R
TP_ON | 17.20 | -15.12 | 0.00 | HECTOR_WATCH_1_TPTP20R | HECTOR_WATCH_1_TP20R
TP_OP | 21.48 | -8.52 | 0.00 | HECTOR_WATCH_1_TPTP20R | HECTOR_WATCH_1_TP20R
TP_RESET | 17.91 | 5.98 | 0.00 | HECTOR_WATCH_1_TPTP20R | HECTOR_WATCH_1_TP20R
TP_SCL | 18.34 | 8.98 | 0.00 | HECTOR_WATCH_1_TPTP20R | HECTOR_WATCH_1_TP20R
TP_SDA | 17.63 | 16.08 | 0.00 | HECTOR_WATCH_1_TPTP20R | HECTOR_WATCH_1_TP20R
TP_SWDCLK | 20.86 | 5.93 | 0.00 | HECTOR_WATCH_1_TPTP20R | HECTOR_WATCH_1_TP20R
TP_SWDIO | 12.04 | -3.42 | 0.00 | HECTOR_WATCH_1_TPTP20R | HECTOR_WATCH_1_TP20R
TP_SWO | 12.00 | -6.02 | 0.00 | HECTOR_WATCH_1_TPTP20R | HECTOR_WATCH_1_TP20R
TP_VBAT | -19.21 | 13.78 | 0.00 | HECTOR_WATCH_1_TPTP20R | HECTOR_WATCH_1_TP20R
TP_VREG | 15.05 | 15.08 | 0.00 | HECTOR_WATCH_1_TPTP20R | HECTOR_WATCH_1_TP20R
U1 | 4.33 | 0.12 | 0.00 | NORDIC_NRF_4_NRF52840_QF | NORDIC_NRF_4_AQFN50P700X700X85_HS-74N
U3 | -7.85 | 15.04 | 0.00 | ESP32_C6_LIBRARY_MAX17048G+T10 | ESP32_C6_LIBRARY_SON50P200X200X80-9N
X1 | 5.01 | 8.14 | 0.00 | 32MHz | NORDIC_NRF_BT-XTAL_2016_N
X2 | -1.36 | 0.46 | 270.00 | 32.768kHz | NORDIC_NRF_1_XTAL_3215_N

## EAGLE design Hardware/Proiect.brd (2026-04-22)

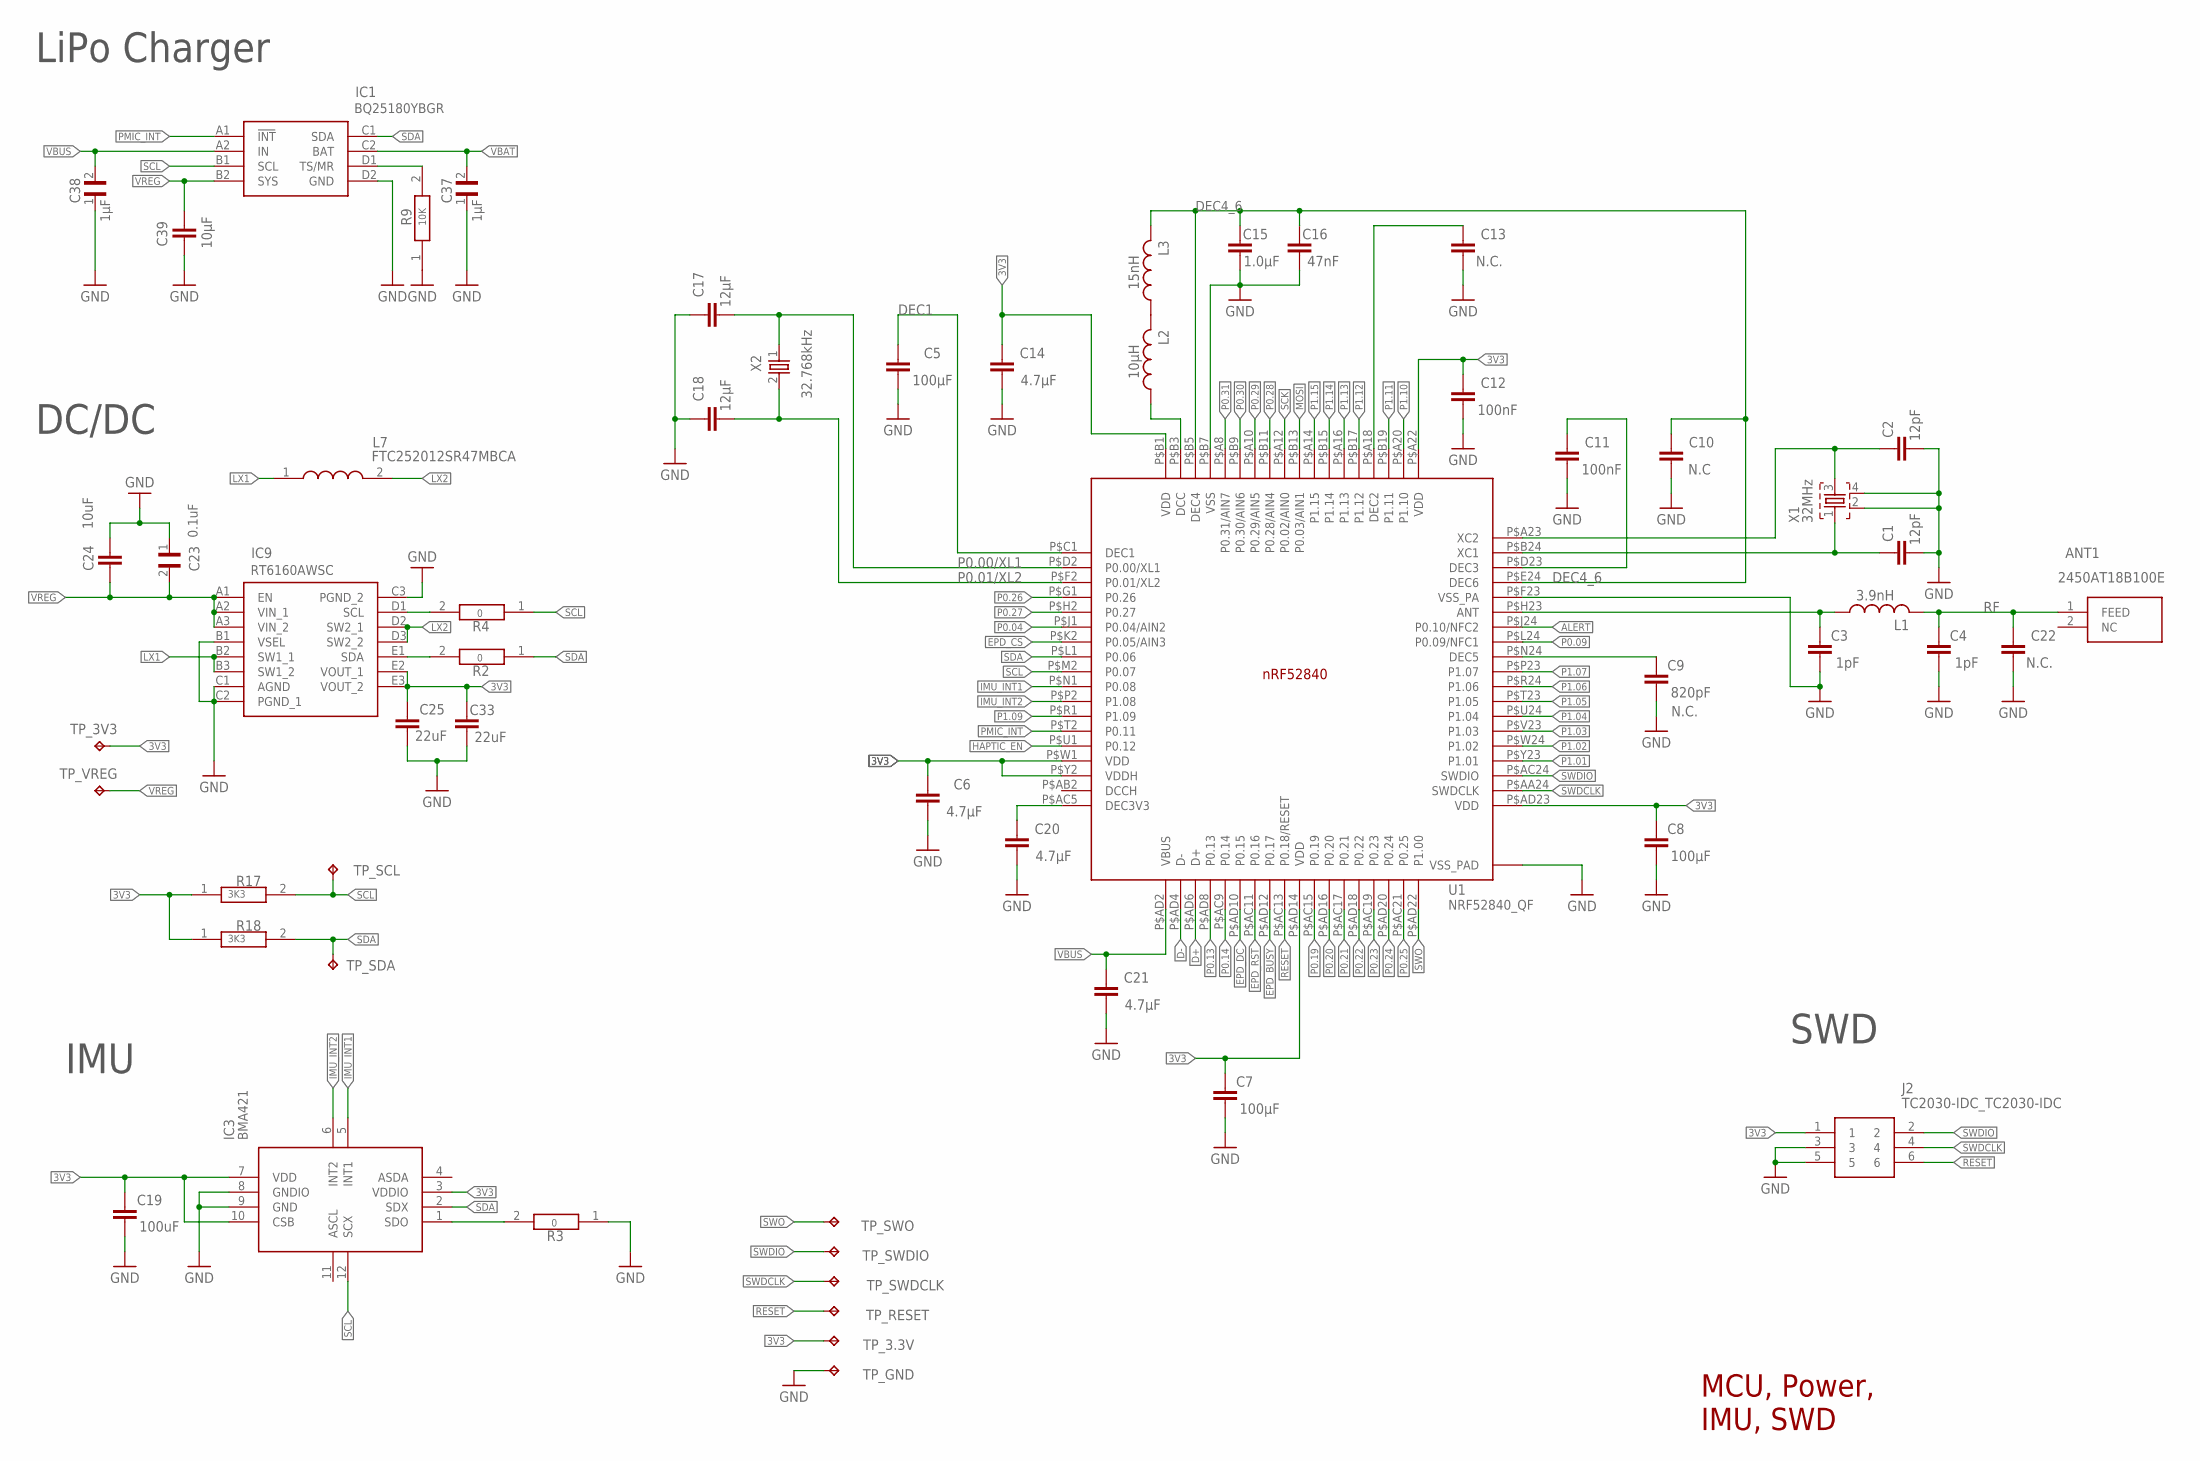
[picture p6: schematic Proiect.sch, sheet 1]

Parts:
ANT1: 2450AT18B100E_2450AT18B100E; 2450AT18B100E_ANTC3216X140N
C1, C2: 12pF; NORDIC_NRF_3_RESC0201_L
C3, C4: 1pF; NORDIC_NRF_3_RESC0201_L
C5, C7, C8: 100µF; NORDIC_NRF_3_RESC0201_L
C6, C14, C20, C21: 4.7µF; NORDIC_NRF_3_RESC0201_L
C9: 820pF; NORDIC_NRF_3_RESC0201_L
C10: N.C; NORDIC_NRF_3_RESC0201_L
C11, C12: 100nF; NORDIC_NRF_3_RESC0201_L
C13, C22: N.C.; NORDIC_NRF_3_RESC0201_L
C15: 1.0µF; NORDIC_NRF_3_RESC0201_L
C16: 47nF; NORDIC_NRF_3_RESC0201_L
C17, C18: 12µF; NORDIC_NRF_3_RESC0201_L
C19: 100uF; NORDIC_NRF_3_RESC0201_L
C23, C37, C38: GRM011R60J152KE01L_2_GRM011R60J152KE01L; GRM011R60J152KE01L_2_CAPC0201X13N
C24: 10uF; NORDIC_NRF_3_RESC0201_L
C25, C33: 22uF; NORDIC_NRF_3_RESC0201_L
C39: 10µF; NORDIC_NRF_3_RESC0201_L
IC1: BQ25180YBGR_BQ25180YBGR; BQ25180YBGR_BGA8C40P2X4_100X155X50
IC3: BMA423_BMA423
IC9: RT6160AWSC_RT6160AWSC; RT6160AWSC_BGA15C40P3X5_140X230X60
J2: TC2030-IDC_TC2030-IDC; TC2030-IDC_TC2030IDC
L1: 3.9nH; NORDIC_NRF_2_RESC0402_L
L2: 10µH; NORDIC_NRF_2_RESC0402_L
L3: 15nH; NORDIC_NRF_2_RESC0402_L
L7: MLP2016SR47MT0S1_FTC252012SR47MBCA; MLP2016SR47MT0S1_INDC2016X100N
R2, R3, R4, R9, R17, R18: ERA-1AEB3401C_CPF0201D7K68C1; ERA-1AEB3401C_0201
TP_3.3V, TP_3V3: HECTOR_WATCH_1_TPTP20R; HECTOR_WATCH_1_TP20R
TP_GND: HECTOR_WATCH_1_TPTP20R; HECTOR_WATCH_1_TP20R
TP_RESET: HECTOR_WATCH_1_TPTP20R; HECTOR_WATCH_1_TP20R
TP_SCL: HECTOR_WATCH_1_TPTP20R; HECTOR_WATCH_1_TP20R
TP_SDA: HECTOR_WATCH_1_TPTP20R; HECTOR_WATCH_1_TP20R
TP_SWDCLK: HECTOR_WATCH_1_TPTP20R; HECTOR_WATCH_1_TP20R
TP_SWDIO: HECTOR_WATCH_1_TPTP20R; HECTOR_WATCH_1_TP20R
TP_SWO: HECTOR_WATCH_1_TPTP20R; HECTOR_WATCH_1_TP20R
TP_VREG: HECTOR_WATCH_1_TPTP20R; HECTOR_WATCH_1_TP20R
U1: NORDIC_NRF_4_NRF52840_QF; NORDIC_NRF_4_AQFN50P700X700X85_HS-74N
X1: 32MHz; NORDIC_NRF_BT-XTAL_2016_N
X2: 32.768kHz; NORDIC_NRF_1_XTAL_3215_N

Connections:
3V3: C6.1, C7.1, C8.1, C12.1, C14.1, C19.1, C25.1, C33.1, IC3.3 (VDDIO), IC3.7 (VDD), IC3.10 (CSB), IC9.E2 (VOUT_1), IC9.E3 (VOUT_2), J2.1, R17.1, R18.1, TP_3.3V.TP, TP_3V3.TP, U1.P$A22 (VDD), U1.P$AD14 (VDD), U1.P$AD23 (VDD), U1.P$B1 (VDD), U1.P$W1 (VDD), U1.P$Y2 (VDDH); also elsewhere on the board
ALERT: U1.P$J24 (P0.10/NFC2); also elsewhere on the board
D+: U1.P$AD6 (D+); also elsewhere on the board
D-: U1.P$AD4 (D-); also elsewhere on the board
DEC1: C5.1, U1.P$C1 (DEC1)
DEC4_6: C10.1, C15.1, C16.1, L3.2, U1.P$B5 (DEC4), U1.P$E24 (DEC6)
EPD_BUSY: U1.P$AD12 (P0.17); also elsewhere on the board
EPD_CS: U1.P$K2 (P0.05/AIN3); also elsewhere on the board
EPD_DC: U1.P$AD10 (P0.15); also elsewhere on the board
EPD_RST: U1.P$AC11 (P0.16); also elsewhere on the board
GND: C1.2, C2.2, C3.2, C4.2, C5.2, C6.2, C7.2, C8.2, C9.2, C10.2, C11.2, C12.2, C13.2, C14.2, C15.2, C16.2, C17.1, C18.1, C19.2, C20.2, C21.2, C22.2, C23.1, C24.1, C25.2, C33.2, C37.1, C38.1, C39.2, IC1.D2 (GND), IC3.8 (GNDIO), IC3.9 (GND), IC9.B1 (VSEL), IC9.C1 (AGND), IC9.C2 (PGND_1), IC9.C3 (PGND_2), J2.3, J2.5, R3.1, R9.1, TP_GND.TP, U1.P$74 (VSS_PAD), U1.P$75 (VSS_PAD), U1.P$76 (VSS_PAD), U1.P$77 (VSS_PAD), U1.P$78 (VSS_PAD), U1.P$79 (VSS_PAD), U1.P$80 (VSS_PAD), U1.P$81 (VSS_PAD), U1.P$82 (VSS_PAD), U1.P$83 (VSS_PAD), U1.P$84 (VSS_PAD), U1.P$85 (VSS_PAD), U1.P$86 (VSS_PAD), U1.P$87 (VSS_PAD), U1.P$88 (VSS_PAD), U1.P$89 (VSS_PAD), U1.P$90 (VSS_PAD), U1.P$B7 (VSS), U1.P$F23 (VSS_PA), X1.2, X1.4; also elsewhere on the board
HAPTIC_EN: U1.P$U1 (P0.12); also elsewhere on the board
IMU_INT1: IC3.5 (INT1), U1.P$N1 (P0.08)
IMU_INT2: IC3.6 (INT2), U1.P$P2 (P1.08)
LX1: IC9.B2 (SW1_1), IC9.B3 (SW1_2), L7.1
LX2: IC9.D2 (SW2_1), IC9.D3 (SW2_2), L7.2
MOSI: U1.P$B13 (P0.03/AIN1); also elsewhere on the board
unnamed: IC3.1 (SDO), R3.2
unnamed: IC1.D1 (TS/MR), R9.2
unnamed: IC9.E1 (SDA), R2.2
unnamed: IC9.D1 (SCL), R4.2
unnamed: L2.1, U1.P$B3 (DCC)
unnamed: L2.2, L3.1
unnamed: C13.1, U1.P$A18 (DEC2)
unnamed: C9.1, U1.P$N24 (DEC5)
unnamed: C11.1, U1.P$D23 (DEC3)
unnamed: C3.1, L1.1, U1.P$H23 (ANT)
unnamed: C2.1, U1.P$A23 (XC2), X1.3
unnamed: C1.1, U1.P$B24 (XC1), X1.1
P0.00/XL1: C17.2, U1.P$D2 (P0.00/XL1), X2.1
P0.01/XL2: C18.2, U1.P$F2 (P0.01/XL2), X2.2
P0.04: U1.P$J1 (P0.04/AIN2)
P0.09: U1.P$L24 (P0.09/NFC1)
P0.13: U1.P$AD8 (P0.13); also elsewhere on the board
P0.14: U1.P$AC9 (P0.14); also elsewhere on the board
P0.19: U1.P$AC15 (P0.19)
P0.20: U1.P$AD16 (P0.20)
P0.21: U1.P$AC17 (P0.21)
P0.22: U1.P$AD18 (P0.22)
P0.23: U1.P$AC19 (P0.23)
P0.24: U1.P$AD20 (P0.24)
P0.25: U1.P$AC21 (P0.25)
P0.26: U1.P$G1 (P0.26)
P0.27: U1.P$H2 (P0.27)
P0.28: U1.P$B11 (P0.28/AIN4)
P0.29: U1.P$A10 (P0.29/AIN5)
P0.30: U1.P$B9 (P0.30/AIN6)
P0.31: U1.P$A8 (P0.31/AIN7)
P1.01: U1.P$Y23 (P1.01); also elsewhere on the board
P1.02: U1.P$W24 (P1.02); also elsewhere on the board
P1.03: U1.P$V23 (P1.03)
P1.04: U1.P$U24 (P1.04)
P1.05: U1.P$T23 (P1.05)
P1.06: U1.P$R24 (P1.06)
P1.07: U1.P$P23 (P1.07)
P1.09: U1.P$R1 (P1.09)
P1.10: U1.P$A20 (P1.10)
P1.11: U1.P$B19 (P1.11)
P1.12: U1.P$B17 (P1.12)
P1.13: U1.P$A16 (P1.13)
P1.14: U1.P$B15 (P1.14)
P1.15: U1.P$A14 (P1.15)
PMIC_INT: IC1.A1 (!INT), U1.P$T2 (P0.11)
RESET: J2.6, TP_RESET.TP, U1.P$AC13 (P0.18/RESET)
RF: ANT1.1 (FEED), C4.1, C22.1, L1.2
SCK: U1.P$A12 (P0.02/AIN0); also elsewhere on the board
SCL: IC1.B1 (SCL), IC3.12 (SCX), R4.1, R17.2, TP_SCL.TP, U1.P$M2 (P0.07); also elsewhere on the board
SDA: IC1.C1 (SDA), IC3.2 (SDX), R2.1, R18.2, TP_SDA.TP, U1.P$L1 (P0.06); also elsewhere on the board
SWDCLK: J2.4, TP_SWDCLK.TP, U1.P$AA24 (SWDCLK)
SWDIO: J2.2, TP_SWDIO.TP, U1.P$AC24 (SWDIO)
SWO: TP_SWO.TP, U1.P$AD22 (P1.00)
VBAT: C37.2, IC1.C2 (BAT); also elsewhere on the board
VBUS: C21.1, C38.2, IC1.A2 (IN), U1.P$AD2 (VBUS); also elsewhere on the board
VBUS/2.6D1: C20.1, U1.P$AC5 (DEC3V3)
VREG: C23.2, C24.2, C39.1, IC1.B2 (SYS), IC9.A1 (EN), IC9.A2 (VIN_1), IC9.A3 (VIN_2), TP_VREG.TP

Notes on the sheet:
LiPo Charger
MCU, Power, IMU, SWD
DC/DC
IMU
SWD

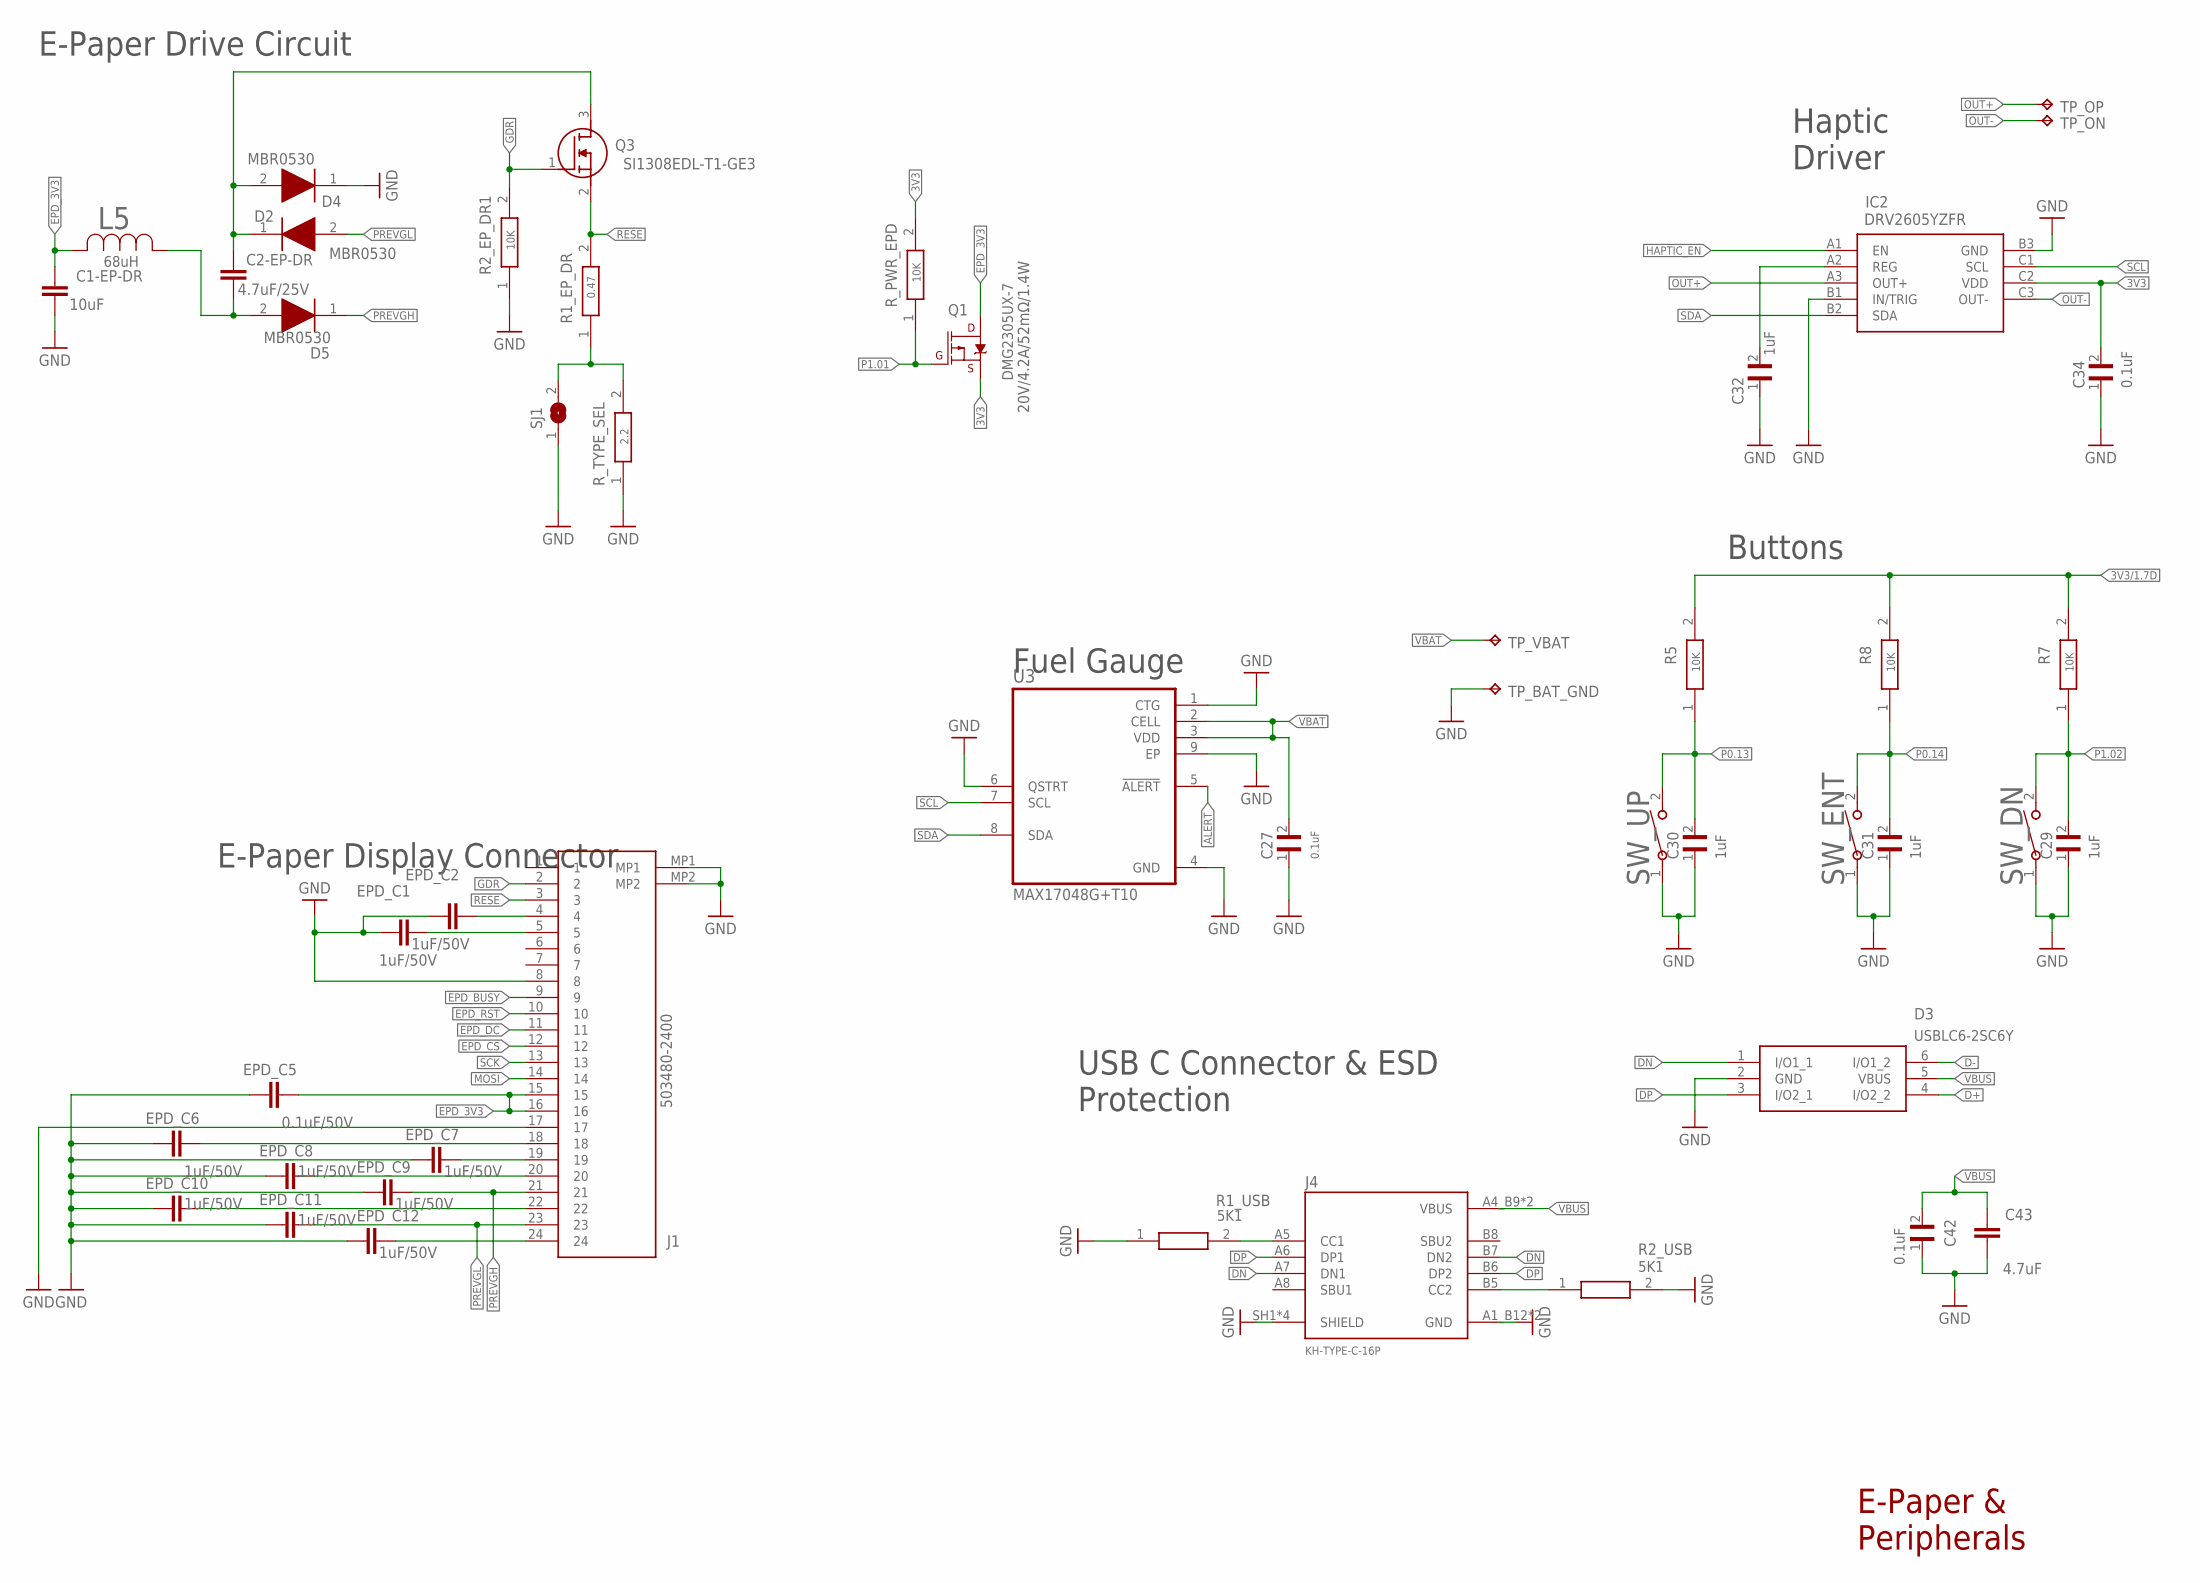
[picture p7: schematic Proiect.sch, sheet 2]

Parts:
C1-EP-DR: 10uF; NORDIC_NRF_3_RESC0201_L
C2-EP-DR: 4.7uF/25V; NORDIC_NRF_3_RESC0201_L
C27, C29, C30, C31, C32, C34, C42: GRM011R60J152KE01L_2_GRM011R60J152KE01L; GRM011R60J152KE01L_2_CAPC0201X13N
C43: 4.7uF; NORDIC_NRF_3_RESC0201_L
D2, D4, D5: ESP32_C6_LIBRARY_5_MBR0530; ESP32_C6_LIBRARY_5_SOD3716X135N
D3: ESP32_C6_LIBRARY_3_USBLC6-2SC6Y; ESP32_C6_LIBRARY_3_SOT95P280X145-6N
EPD_C1, EPD_C2, EPD_C6, EPD_C7, EPD_C8, EPD_C9, EPD_C10, EPD_C11, EPD_C12: 1uF/50V; NORDIC_NRF_3_RESC0201_L
EPD_C5: 0.1uF/50V; NORDIC_NRF_3_RESC0201_L
IC2: DRV2605YZFR_DRV2605YZFR; DRV2605YZFR_BGA9C50P3X3_144X144X62
J1: 503480-2400_503480-2400; 503480-2400_5034802400
J4: KH-TYPE-C-16P_KH-TYPE-C-16P; KH-TYPE-C-16P_KINGHELM_KH-TYPE-C-16P
L5: ESP32_C6_LIBRARY_2_744043680IND_4828-WE-TPC_WRE; ESP32_C6_LIBRARY_2_IND_4828-WE-TPC_WRE
Q1: 20V/4.2A/52mΩ/1.4W; ESP32_C6_LIBRARY_4_ESP32_C6_LIBRARY_4_ESP32_C6_LIBRARY_4_ES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
Q3: ESP32_C6_LIBRARY_6_SI1308EDL-T1-GE3; ESP32_C6_LIBRARY_6_SOT65P210X110-3N
R1_EP_DR, R1_USB, R2_EP_DR1, R2_USB, R5, R7, R8: ERA-1AEB3401C_CPF0201D7K68C1; ERA-1AEB3401C_0201
R_PWR_EPD: ERA-1AEB3401C_CPF0201D7K68C1; ERA-1AEB3401C_0201
R_TYPE_SEL: ERA-1AEB3401C_CPF0201D7K68C1; ERA-1AEB3401C_0201
SJ1: ESP32_C6_LIBRARY_7_JUMPER_SJ
SW_DN: 2025-10-22_07-23-44_LIBRARY_EVP-AKE31ASW_EVP-AKE3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; 2025-10-22_07-23-44_LIBRARY_SW_EVP-AKE31A_PAN
SW_ENT: 2025-10-22_07-23-44_LIBRARY_EVP-AKE31ASW_EVP-AKE3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; 2025-10-22_07-23-44_LIBRARY_SW_EVP-AKE31A_PAN
SW_UP: 2025-10-22_07-23-44_LIBRARY_EVP-AKE31ASW_EVP-AKE3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; 2025-10-22_07-23-44_LIBRARY_SW_EVP-AKE31A_PAN
TP_BAT_GND: HECTOR_WATCH_1_TPTP20R; HECTOR_WATCH_1_TP20R
TP_ON: HECTOR_WATCH_1_TPTP20R; HECTOR_WATCH_1_TP20R
TP_OP: HECTOR_WATCH_1_TPTP20R; HECTOR_WATCH_1_TP20R
TP_VBAT: HECTOR_WATCH_1_TPTP20R; HECTOR_WATCH_1_TP20R
U3: ESP32_C6_LIBRARY_MAX17048G+T10; ESP32_C6_LIBRARY_SON50P200X200X80-9N

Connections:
3V3: C34.2, IC2.C2 (VDD), Q1.2 (S), R_PWR_EPD.2; also elsewhere on the board
3V3/1.7D: R5.2, R7.2, R8.2
ALERT: U3.5 (!ALERT); also elsewhere on the board
D+: D3.4 (I/O2_2); also elsewhere on the board
D-: D3.6 (I/O1_2); also elsewhere on the board
DN: D3.1 (I/O1_1), J4.A7 (DN1), J4.B7 (DN2)
DP: D3.3 (I/O2_1), J4.A6 (DP1), J4.B6 (DP2)
EPD_3V3: C1-EP-DR.1, EPD_C5.2, J1.15, J1.16, L5.2, Q1.3 (D)
EPD_BUSY: J1.9; also elsewhere on the board
EPD_CS: J1.12; also elsewhere on the board
EPD_DC: J1.11; also elsewhere on the board
EPD_RST: J1.10; also elsewhere on the board
GDR: J1.2, Q3.1 (G), R2_EP_DR1.2
GND: C1-EP-DR.2, C27.1, C29.1, C30.1, C31.1, C32.1, C34.1, C42.1, C43.2, D3.2 (GND), D4.1 (K), EPD_C1.1, EPD_C2.1, EPD_C5.1, EPD_C6.1, EPD_C7.1, EPD_C8.1, EPD_C9.1, EPD_C10.1, EPD_C11.1, EPD_C12.1, IC2.B1 (IN/TRIG), IC2.B3 (GND), J1.8, J1.17, J1.MP1, J1.MP2, J4.A1_B12 (GND), J4.A12_B1 (GND), J4.SH1 (SHIELD), J4.SH2 (SHIELD), J4.SH3 (SHIELD), J4.SH4 (SHIELD), R1_USB.1, R2_EP_DR1.1, R2_USB.2, R_TYPE_SEL.1, SJ1.1, SW_DN.1, SW_ENT.1, SW_UP.1, TP_BAT_GND.TP, U3.1 (CTG), U3.4 (GND), U3.6 (QSTRT), U3.9 (EP); also elsewhere on the board
HAPTIC_EN: IC2.A1 (EN); also elsewhere on the board
MOSI: J1.14; also elsewhere on the board
unnamed: C2-EP-DR.2, D5.2 (A), L5.1
unnamed: C2-EP-DR.1, D2.1 (K), D4.2 (A), Q3.3 (D)
unnamed: R1_EP_DR.1, R_TYPE_SEL.2, SJ1.2
unnamed: EPD_C2.2, J1.4
unnamed: EPD_C6.2, J1.18
unnamed: EPD_C1.2, J1.5
unnamed: EPD_C7.2, J1.19
unnamed: EPD_C8.2, J1.20
unnamed: EPD_C10.2, J1.22
unnamed: EPD_C12.2, J1.24
unnamed: C32.2, IC2.A2 (REG)
unnamed: J4.A5 (CC1), R1_USB.2
unnamed: J4.B5 (CC2), R2_USB.1
OUT+: IC2.A3 (OUT+), TP_OP.TP
OUT-: IC2.C3 (OUT-), TP_ON.TP
P0.13: C30.2, R5.1, SW_UP.2; also elsewhere on the board
P0.14: C31.2, R8.1, SW_ENT.2; also elsewhere on the board
P1.01: Q1.1 (G), R_PWR_EPD.1; also elsewhere on the board
P1.02: C29.2, R7.1, SW_DN.2; also elsewhere on the board
PREVGH: D5.1 (K), EPD_C9.2, J1.21
PREVGL: D2.2 (A), EPD_C11.2, J1.23
RESE: J1.3, Q3.2 (S), R1_EP_DR.2
SCK: J1.13; also elsewhere on the board
SCL: IC2.C1 (SCL), U3.7 (SCL); also elsewhere on the board
SDA: IC2.B2 (SDA), U3.8 (SDA); also elsewhere on the board
VBAT: C27.2, TP_VBAT.TP, U3.2 (CELL), U3.3 (VDD); also elsewhere on the board
VBUS: C42.2, C43.1, D3.5 (VBUS), J4.A4_B9 (VBUS), J4.A9_B4 (VBUS); also elsewhere on the board

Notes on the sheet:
E-Paper Drive Circuit
E-Paper & Peripherals
E-Paper Display Connector
Fuel Gauge
Haptic Driver
Buttons
USB C Connector & ESD Protection

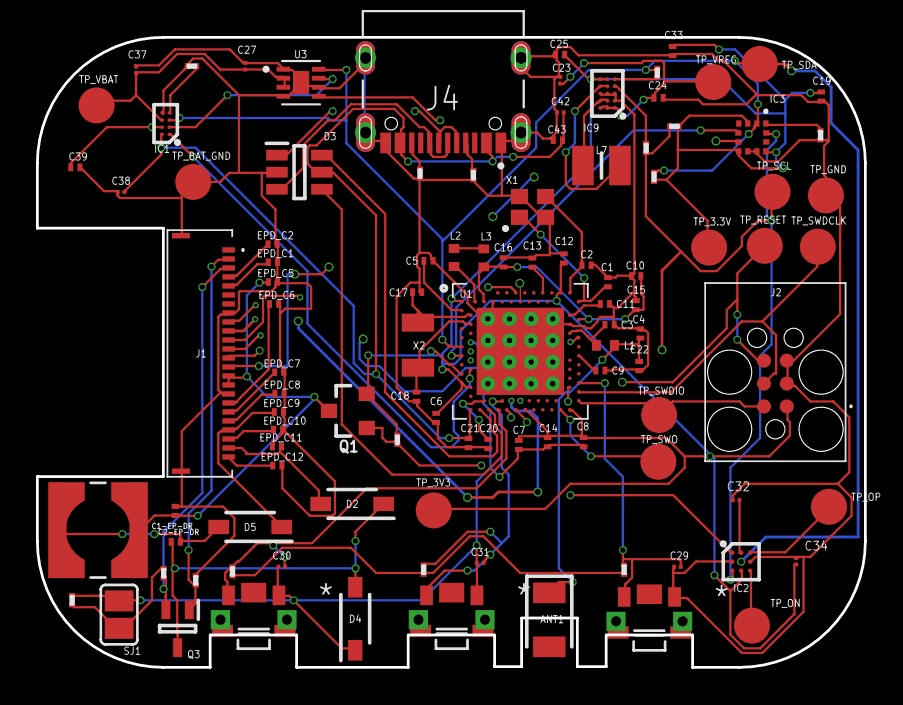
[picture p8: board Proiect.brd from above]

Board: 4 copper layers, 46.0 x 35.0 mm, 105 parts (0 on the bottom side), 71 nets.

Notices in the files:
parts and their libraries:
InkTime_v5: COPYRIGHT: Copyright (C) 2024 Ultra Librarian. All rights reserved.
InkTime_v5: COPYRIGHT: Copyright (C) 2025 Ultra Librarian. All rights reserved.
